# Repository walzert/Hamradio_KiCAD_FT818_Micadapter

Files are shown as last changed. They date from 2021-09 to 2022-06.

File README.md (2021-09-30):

# Hamradio_KiCAD_FT818_Micadapter

A simple Y-splitter for the RJ45 microfon plug of the FT818 should work with same pinout.
It routes 1:1 and breaks the pins out in pair with ground. 

The adpater could be used to connect a XLR microfon and buttons instead of the original MH31 mic. It also could be used for connecting a mircocontroller to that and build 
something like the MH-36E8J, deeper research for the commands is important.

Routing could be changed / extended add don't care about the FST/DWN/UP buttons and rout audio over CAT5 cable.

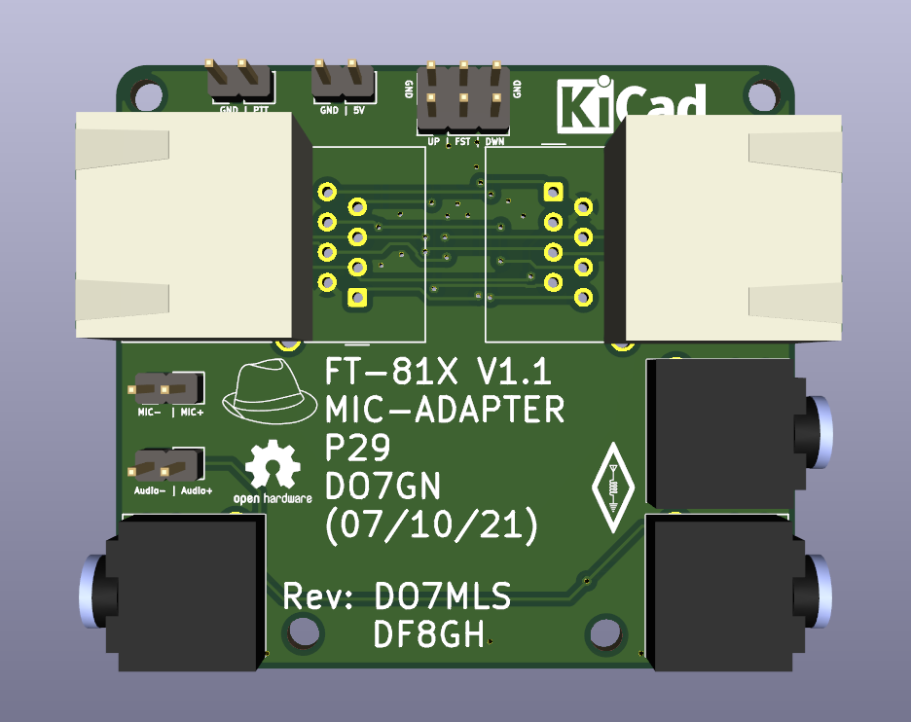
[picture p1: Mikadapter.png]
Mikadapter


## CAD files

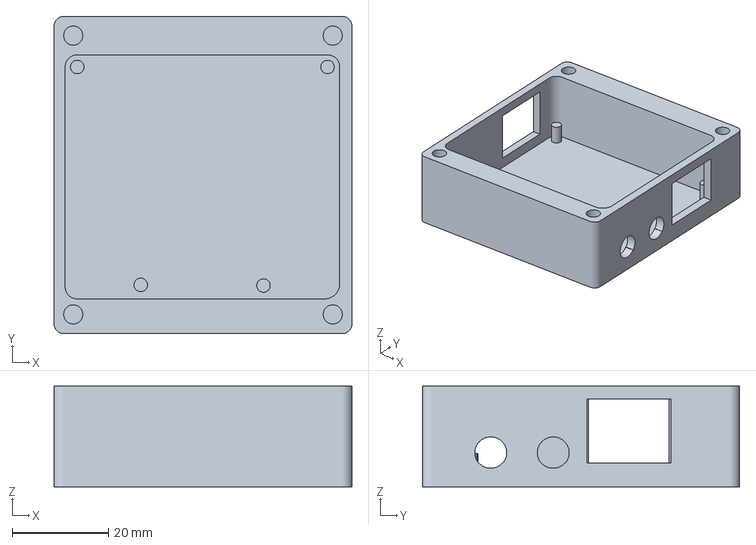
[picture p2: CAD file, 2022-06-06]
3D/Mikadapter81X_V2-Fusion.amf
62.0 x 66.0 x 21.0 mm

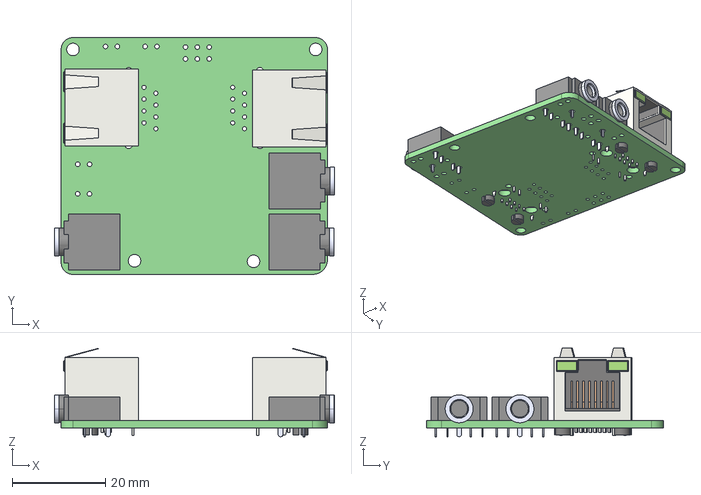
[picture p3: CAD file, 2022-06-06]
PCB/Mikadapter.step
60.1 x 50.8 x 19.0 mm
_autosave-Mikadapter PCB

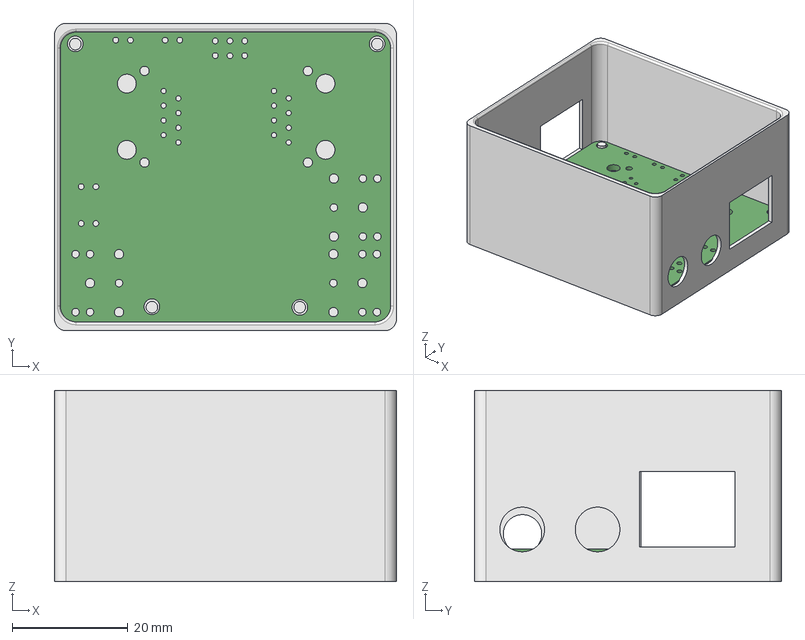
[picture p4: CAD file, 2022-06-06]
3D/cASE.FCStd
59.0 x 53.0 x 33.0 mm
Mikadapter PCB

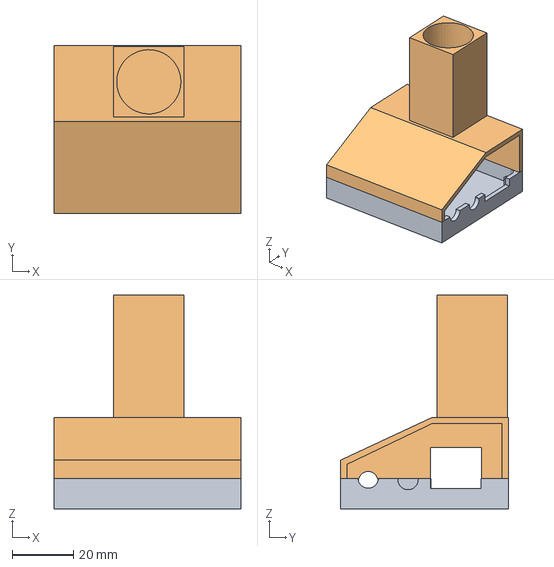
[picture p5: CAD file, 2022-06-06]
PCB/FT81X-Mic.FCStd
61.1 x 54.8 x 70.0 mm

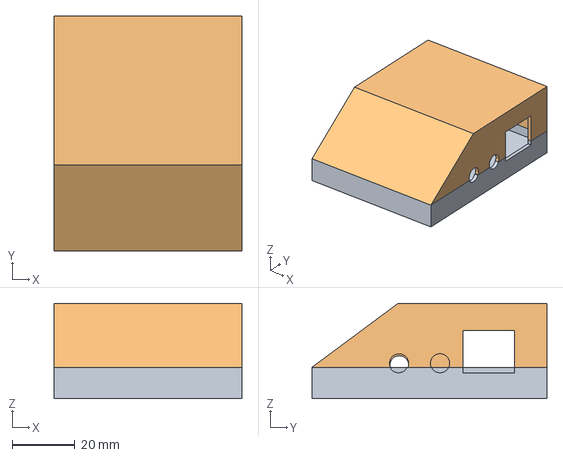
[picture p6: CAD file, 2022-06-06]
3D/Mikadapter81X.FCStd
60.0 x 75.0 x 30.4 mm

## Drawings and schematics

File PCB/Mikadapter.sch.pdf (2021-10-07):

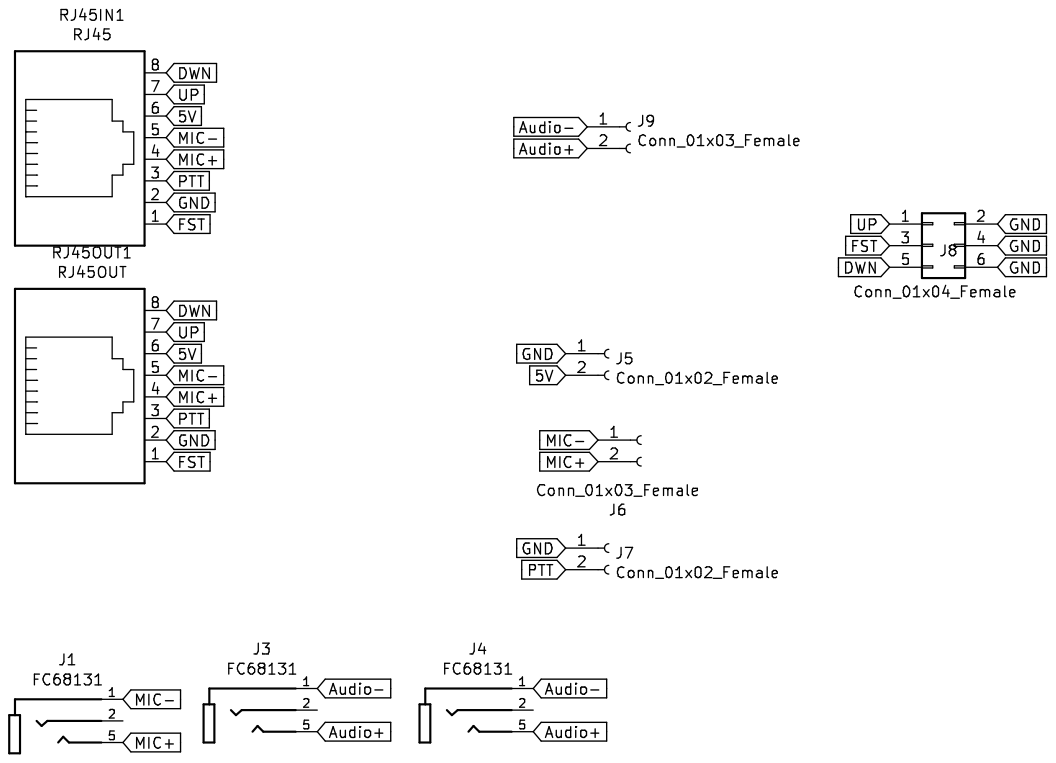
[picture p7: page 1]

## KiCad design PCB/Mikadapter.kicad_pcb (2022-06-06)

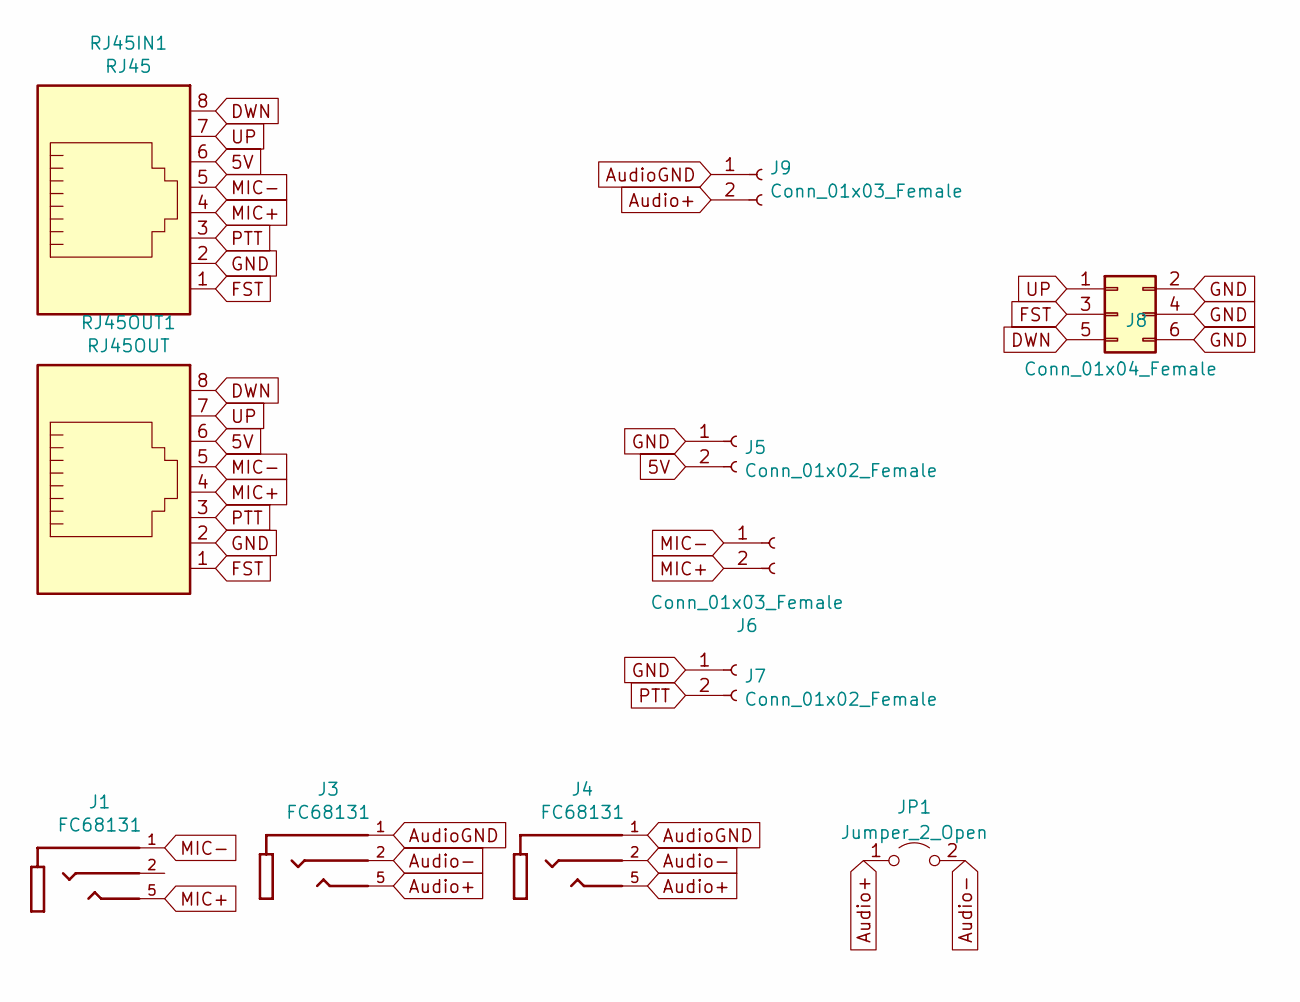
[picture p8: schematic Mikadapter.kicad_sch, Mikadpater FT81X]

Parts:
J1, J3, J4: FC68131; CLIFF_FC68131; PARTREV 5
J5, J7: Conn_01x02_Female; PinHeader_1x02_P2.54mm_Vertical
J6, J9: Conn_01x03_Female; PinHeader_1x02_P2.54mm_Vertical
J8: Conn_01x04_Female; PinHeader_2x03_P2.54mm_Vertical
JP1: Jumper_2_Open; SolderJumper-2_P1.3mm_Open_TrianglePad1.0x1.5mm
RJ45IN1: RJ45; RJ45_Wuerth_7499010001A_Horizontal
RJ45OUT1: RJ45OUT; RJ45_Wuerth_7499010001A_Horizontal

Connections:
5V: J5.2, RJ45IN1.6, RJ45OUT1.6
Audio+: J3.5, J4.5, J9.2, JP1.1 (A)
Audio-: J3.2, J4.2, JP1.2 (B)
AudioGND: J3.1, J4.1, J9.1
DWN: J8.5, RJ45IN1.8, RJ45OUT1.8
FST: J8.3, RJ45IN1.1, RJ45OUT1.1
GND: J5.1, J7.1, J8.2, J8.4, J8.6, RJ45IN1.2, RJ45OUT1.2
MIC+: J1.5, J6.2, RJ45IN1.4, RJ45OUT1.4
MIC-: J1.1, J6.1, RJ45IN1.5, RJ45OUT1.5
PTT: J7.2, RJ45IN1.3, RJ45OUT1.3
UP: J8.1, RJ45IN1.7, RJ45OUT1.7

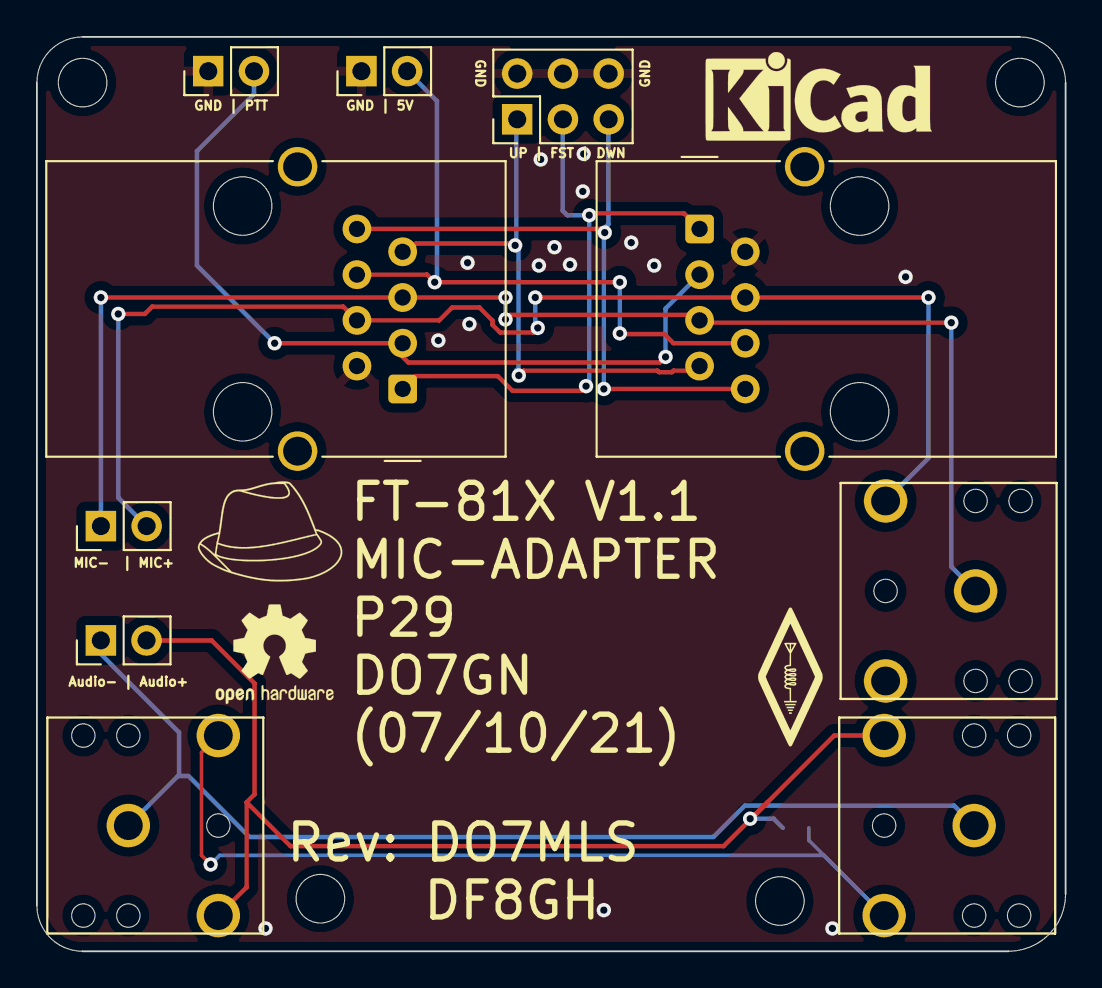
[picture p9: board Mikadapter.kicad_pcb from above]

Board: 2 copper layers, 57.1 x 50.8 mm, 12 parts (1 on the bottom side), 11 nets.

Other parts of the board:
e: OSHW-Logo2_7.3x6mm_SilkScreen

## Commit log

2021-04-09 Upload V1
    [Mikadapter.kicad_pcb, Mikadapter.sch]
2021-04-09 changed width of 5V trace and pinout on the sides
    [Mikadapter.kicad_pcb]
2021-04-09 changed layout for FST|DWN|UP buttons
    [Mikadapter.kicad_pcb, Mikadapter.sch]
2021-09-30 transformed in KiCAD 6 and changed layout and changed pinout for RJ45
    [Mikadapter.kicad_pcb, Mikadapter.kicad_sch, Mikadapter.sch]
2021-09-30 added schema as PDF and changed schema informations
    [Mikadapter.kicad_sch]
2021-10-01 changed name to ft-81x
    [Mikadapter.kicad_pcb]
2021-10-07 Changed Audio pins after inspection of the jack
    [Mikadapter.kicad_pcb, Mikadapter.kicad_sch]
2022-06-06 Added trace for second Audio channel, new folder, 3D
    [FT81X-Mic.FCStd, Mikadapter.kicad_pcb, Mikadapter.kicad_sch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]
2022-06-06 Updated PCB Image
